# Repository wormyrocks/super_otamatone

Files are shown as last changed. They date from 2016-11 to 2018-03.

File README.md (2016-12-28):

# super_otamatone

Because the world needs a better Otamatone.

In order to set up build environment, you must have three .mk files from the Arduino Makefile repository in arduino/build_scripts

Teensy.mk
Common.mk
Arduino.mk

https://github.com/sudar/Arduino-Makefile

Running setup.sh in that directory should download them automatically.
You also need the Arduino application and Teensyduino, as well as the libraries specified in the Makefile.

This library uses my fork of the arduino-menusystem library, which can be found here.
https://github.com/wormyrocks/arduino-menusystem

It is included as a submodule.

'upload' script automates compilation, upload, and opening the serial monitor.

The last two require the tyc program. Find binaries here. https://github.com/Koromix/ty/releases
tyc should also be in /arduino/otamatone.

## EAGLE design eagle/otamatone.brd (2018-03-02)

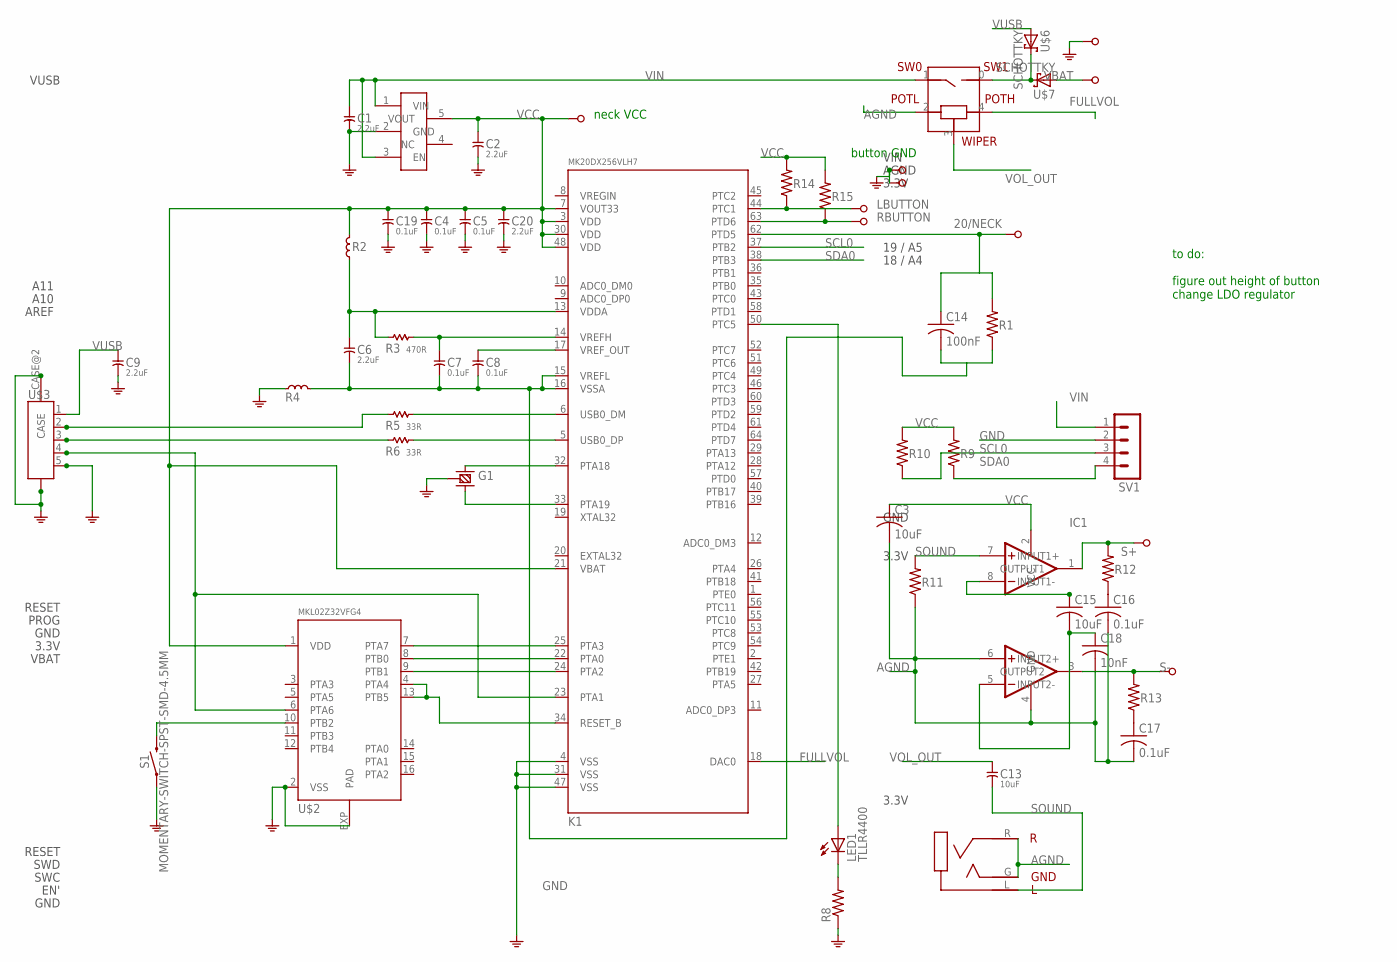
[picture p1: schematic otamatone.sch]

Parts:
B+: PIN; PTH_39MIL
B-: PIN; PTH_39MIL
C1, C2, C6, C9, C20: 2.2uF; C0603
C3, C13, C15: 10uF; C0603
C4, C5, C7, C8, C19: 0.1uF; C0402
C14: 100nF; C0402
C16, C17: 0.1uF; C0603
C18: 10nF; C0603
G1: CRYSTAL-; CRYS
IC1: TDA2822MSOP8; SOP8
K1: MK20DX256VLH7; LQFP64-05
LED1: TLLR4400; LED3MM
R1: 62K; R0402
R2, R4: FERRITE; L0603
R3: 470R; R0402
R5, R6: 33R; R0402
R8: R-US_R0603; R0603
R9, R10, R14, R15: 10K; R0402
R11: 10K; R0603
R12, R13: 4.7; R0603
S1: MOMENTARY-SWITCH-SPST-SMD-4.5MM; TACTILE_SWITCH_SMD_4.5MM
S+: PINSMT; SMD
S-: PINSMT; SMD
SV1: MA04-1
SX1, SX2, SX3, SX4: PIN; PTH_39MIL
U$1: P170S; 5PIN_POT
U$2: MKL02Z32VFG4; QFN16
U$3: VERT_USB; TALL_BOI
U$4: VERT_JACK; AUDIOJACK
U$5: AP2112K; SOT25
U$6, U$7: SCHOTTKY; LED-0805
Z+: PINSMT; SMD
Z-: PINSMT; SMD

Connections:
20/NECK: C14.1, K1.62 (PTD5), R1.2, Z-.P$1
AGND: C3.2, C6.2, C7.2, C8.2, C14.2, C16.2, C17.2, C18.2, IC1.4 (GND), IC1.6 (INPUT2+), K1.15 (VREFL), K1.16 (VSSA), R1.1, R4.2, R11.1, U$1.2 (POTL), U$4.G (GND), U$4.R
FULLVOL: K1.18 (DAC0), U$1.4 (POTH)
GND: B-.1, C1.2, C2.2, C4.2, C5.2, C9.2, C19.2, C20.2, G1.P$1 (GND), G1.P$4 (GND), K1.4 (VSS), K1.31 (VSS), K1.47 (VSS), R4.1, R8.1, S1.2 (1), S1.3 (1), SV1.2, SX1.1, SX3.1, U$2.2 (VSS), U$2.EXP (PAD), U$3.5, U$3.CASE, U$3.CASE@2 (CASE), U$5.2 (GND)
LBUTTON: K1.44 (PTC1), R14.1, SX2.1
unnamed: U$1.0 (SW1), U$6.- (C), U$7.- (C)
unnamed: K1.22 (PTA0), U$2.8 (PTB0)
unnamed: K1.24 (PTA2), U$2.9 (PTB1)
unnamed: G1.P$2 (1), K1.32 (PTA18)
unnamed: G1.P$3 (2), K1.33 (PTA19)
unnamed: C15.1, IC1.8 (INPUT1-)
unnamed: K1.25 (PTA3), U$2.7 (PTA7)
unnamed: S1.1 (2), S1.4 (2), U$2.10 (PTB2)
unnamed: C8.1, K1.17 (VREF_OUT)
unnamed: K1.34 (RESET_B), U$2.4 (PTA4), U$2.13 (PTB5)
unnamed: C7.1, K1.14 (VREFH), R3.2
unnamed: C6.1, K1.13 (VDDA), R2.1, R3.1
unnamed: C16.1, R12.1
unnamed: K1.23 (PTA1), U$2.6 (PTA6), U$3.4
unnamed: C17.1, R13.1
unnamed: C15.2, C18.1, IC1.5 (INPUT2-)
unnamed: K1.50 (PTC5), LED1.A
unnamed: LED1.K (C), R8.2
RBUTTON: K1.63 (PTD6), R15.1, SX4.1
S+: IC1.1 (OUTPUT1), R12.2, S+.P$1
S-: IC1.3 (OUTPUT2), R13.2, S-.P$1
SCL0: K1.37 (PTB2), R10.1, SV1.3
SDA0: K1.38 (PTB3), R9.1, SV1.4
SOUND: C13.2, IC1.7 (INPUT1+), R11.2, U$4.L
USB0_DM: K1.6 (USB0_DM), R5.2
USB0_DP: K1.5 (USB0_DP), R6.2
USB_M: R5.1, U$3.2
USB_P: R6.1, U$3.3
VBAT: B+.1, U$7.+ (A)
VCC: C2.1, C3.1, C4.1, C5.1, C19.1, C20.1, IC1.2 (VCC), K1.3 (VDD), K1.7 (VOUT33), K1.21 (VBAT), K1.30 (VDD), K1.48 (VDD), R2.2, R9.2, R10.2, R14.2, R15.2, U$2.1 (VDD), U$5.5 (VOUT), Z+.P$1
VIN: C1.1, SV1.1, U$1.1 (SW0), U$5.1 (VIN), U$5.3 (EN)
VOL_OUT: C13.1, U$1.3 (WIPER)
VUSB: C9.1, U$3.1, U$6.+ (A)

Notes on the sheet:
VIN
AGND
3.3V
19 / A5
18 / A4
GND
VBAT
RESET
PROG
A11
A10
AREF
VUSB
SWD
SWC
EN'
to do: figure out height of button change LDO regulator
neck VCC
button GND

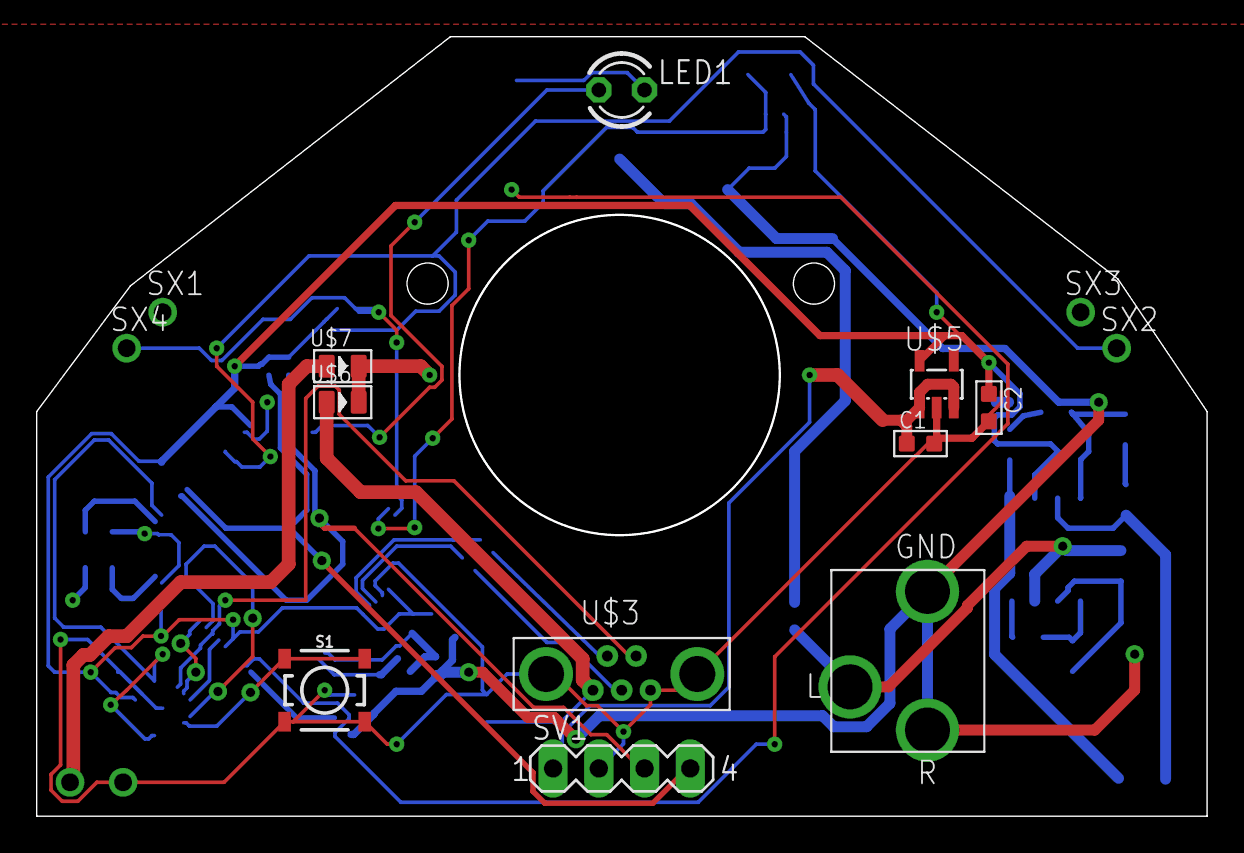
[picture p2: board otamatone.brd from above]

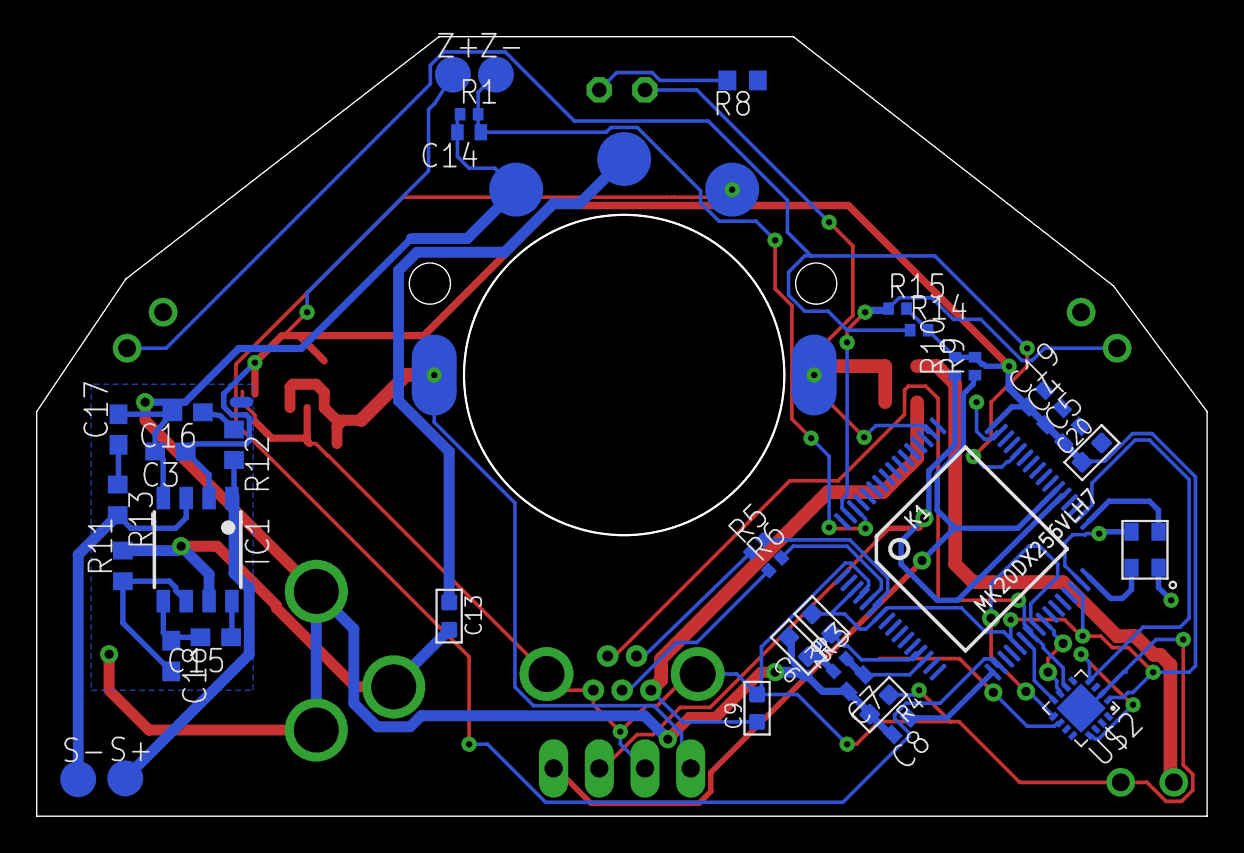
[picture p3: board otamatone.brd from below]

Board: 2 copper layers, 65.0 x 43.3 mm, 54 parts (38 on the bottom side), 38 nets.

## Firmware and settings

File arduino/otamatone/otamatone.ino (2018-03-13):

#include "MenuSystem.h"
#include "Synth.h"
#include "images.h"
#include <Adafruit_SSD1306.h>
Adafruit_SSD1306 oled(4);
// pin values
#define POT_PIN 20 // neck potentiometer reading
#define VOLUME_PIN 23 // volume potentiometer reading
#define BUTTON_LEFT 22 // left button
#define BUTTON_RIGHT 21 // right button
#define POLL_NECK_MICROS 6000 // interval between resistor polls (us)
#define POLL_VOLUME_MICROS 50000 // interval between volume pot polls (us)
#define EVENT_LOOP_DT 10 // time between loop() calls (ms)
// analogRead resolution
#define ADC_RES 16
#define RMIN 17 // minimum neck resistance, in kOhms
#define RMAX 195 // maximum neck resistance, in kOhms
#define PULL 62 // size of pull resistor, in kOhms
// values pertaining to ADC resolution
static const uint16_t max_adc = pow(2, ADC_RES) - 1;
static const uint16_t thresh_adc = max_adc / 10;
static const uint32_t neckscale = max_adc * PULL;
static const uint16_t neckscale_2 = max_adc / (RMAX - RMIN);
static uint16_t dt;
volatile uint16_t _pot_val;
static uint16_t pot_val;
static bool oto_tune_on = false;
static bool scrolling = false;
static bool select_on_release = false;
static bool edit_mode = false;
static bool new_vol = false;
// GUItool: begin automatically generated code
AudioSynthWaveform waveform1; // xy=464.2857360839844,727.8571605682373
AudioEffectEnvelope envelope1; // xy=701.2857360839844,635.8571605682373
AudioMixer4 mixer1; // xy=883,801
AudioOutputAnalog dac1; // xy=1017.1428642272949,667.1428813934326
AudioConnection patchCord1(waveform1, envelope1);
AudioConnection patchCord2(envelope1, 0, mixer1, 0);
AudioConnection patchCord3(mixer1, dac1);
// GUItool: end automatically generated code
Synth synth1(max_adc, & mixer1, & waveform1, & envelope1);
IntervalTimer neck_read_int;
IntervalTimer vol_read_int;
Bounce debounce_1 = Bounce();
Bounce debounce_2 = Bounce();
#include "mymenu.h"
void read_volume()
{
}

void button_1_pressed()
{
  if (edit_mode)
  {
    ms.display();
  }
}

void button_1_released()
{
  if (!edit_mode)
  {
    if (!synth1.playing)
    {
      synth1.change_octave(-1);
      disp_update_non_menu();
    }
  } else {
    ms.back();
    ms.display();
  }
}

void button_2_pressed()
{
  if (edit_mode)
  {
    synth1.mute(true);
    scrolling = true;
    select_on_release = true;
  }
}

void button_2_released()
{
  if (edit_mode)
  {
    synth1.mute(false);
    scrolling = false;
    if (select_on_release)
    {
      ms.select();
      ms.display();
    }
  }
  else
  {
    if (!synth1.playing)
    {
      synth1.change_octave(1);
      disp_update_non_menu();
    }
  }
}

void read_scale_neck()
{
  // resistance of neck, accounting for voltage division: PULL * (max_adc-N)/N
  _pot_val = analogRead(POT_PIN);
  if (_pot_val < thresh_adc)
    _pot_val = 0;
  else
  {
    _pot_val = (neckscale / _pot_val - PULL - RMIN) * neckscale_2;
  }
}

void setup()
{
  AudioMemory(18);
  pinMode(BUTTON_LEFT, INPUT);
  pinMode(BUTTON_RIGHT, INPUT);
  pinMode(POT_PIN, INPUT);
  pinMode(VOLUME_PIN, INPUT);
  // enter edit mode if both buttons are down at startup
  if (digitalRead(BUTTON_LEFT) == 0 && digitalRead(BUTTON_RIGHT) == 0)
  {
    edit_mode = 1;
  }
  edit_mode = 1;
  oled.begin(SSD1306_SWITCHCAPVCC, 0x3C);
  oled.clearDisplay();
  dac1.analogReference(INTERNAL);
  delay(50); // time for DAC voltage stable
  // pinMode(5, OUTPUT);
  // digitalWrite(5, HIGH); // turn on the amplifier
  // delay(10); // allow time to wake up
  debounce_1.attach(BUTTON_LEFT);
  debounce_2.attach(BUTTON_RIGHT);
  debounce_1.interval(5);
  debounce_2.interval(5);
  analogReadResolution(ADC_RES);
  neck_read_int.begin(read_scale_neck, POLL_NECK_MICROS);
  vol_read_int.begin(read_volume, POLL_VOLUME_MICROS);
  synth1.begin();
  presets[0].en = true;
  preset_menu_shown = presets[0].en;
  populate_menus();
  if (edit_mode)
  {
    ms.display();
  }
  else
  {
    oled.drawBitmap(0, 0, otamatone, 128, 64, 1);
    oled.display();
    delay(2000);
    disp_setup();
    disp_update_non_menu();
  }
}

void loop()
{
  debounce_1.update();
  debounce_2.update();
  dt = millis();
  noInterrupts();
  pot_val = _pot_val;
  interrupts();
  synth1.update(pot_val);
  // if (synth1.playing) Serial.println(synth1.get_freq());
  if (debounce_1.risingEdge())
    button_1_released();
  else if (debounce_1.fallingEdge())
    button_1_pressed();
  if (debounce_2.risingEdge())
    button_2_released();
  else if (debounce_2.fallingEdge())
    button_2_pressed();
  update_menu();
  while (millis() - dt < EVENT_LOOP_DT)
  {
  }
}

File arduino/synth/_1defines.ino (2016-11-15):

#include <MenuSystem.h>
#include <Adafruit_SSD1306.h>
#include <Bounce2.h>
#include <math.h>

//pin values
#define OLED_RESET 4              //unused
#define POT_PIN A10               //neck potentiometer reading
#define VOLUME_PIN 15             //volume potentiometer reading
#define BUTTON_LEFT 0             //left button
#define BUTTON_RIGHT 1            //right button

#define RMIN 23                   // minimum neck resistance, in kOhms
#define RMAX 190                  // maximum neck resistance, in kOhms
#define PULL 62                   // size of pull resistor, in kOhms
#define POLL_NECK_MICROS 6000     // interval between resistor polls (us)
#define POLL_VOLUME_MICROS 50000  // interval between volume pot polls (us)
#define EVENT_LOOP_DT 10          // time between loop() calls (ms)
#define FILTER_SIZE 8             // size of moving average buffer

//minimum and maximum frequencies in default range
#define FREQ_MIN_INIT 160.0 
#define FREQ_MAX_INIT 1450.0

//analogRead resolution
#define ADC_RES 16

//values pertaining to ADC resolution
static const int max_adc = pow(2,ADC_RES);
static const int thresh_adc = max_adc/10;

// ***** flags controlling overall state machine ***** //
static bool oto_tune_on = false;
static bool playing = false;
static bool scrolling = false;
static bool select_on_release = false;
static bool edit_mode = false;
static bool new_vol = false;

//ring buffer containing samples in moving average
static int avgs[FILTER_SIZE];

//pointer offset of oldest buffer contents
static int avg_ind = 0;

//time between cycles
static int dt;

//most recent value from potentiometer
static int pot_val;
//current volume
static int vol;

//minimum and maximum frequencies
static float freq_min = FREQ_MIN_INIT;
static float freq_max = FREQ_MAX_INIT;

//constant for equal temperament
static const float a_exp = pow(2, 1/12.0);
static const float log_a_exp = log(2)/12.0;
static const float a_tune = 440;

//current octave
static int octave = 0;
#define MAX_OCT 2
#define MIN_OCT -2

//neck scaling coefficients
static int neckscale = max_adc * PULL;
static int neckscale_2 = max_adc / (RMAX-RMIN);

//frequency coefficients
static float a_coeff;
static float b_coeff;
  
AudioControlSGTL5000 codec;
IntervalTimer neck_read_int;
IntervalTimer vol_read_int;

Bounce debounce_1 = Bounce();
Bounce debounce_2 = Bounce();

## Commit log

2016-10-30 switched to interrupts over polling
    [otamatone.xlsx]
2016-11-07 undid synth table
    [otamatone.xlsx]
2016-11-13 added octave switch functionality
2016-11-14 Begin working on menu framework.
2016-11-14 added sample code for navigating menus on-device
2016-11-14 Remove extraneous menu sample code.
2016-11-15 added oto tune and variable adc res
2016-11-15 compartmentalized arduino code into multiple files
2016-11-28 Add fritzing interposer design (shudder).
    [otamatone_breakout.fzz]
2016-11-28 Small updates to interposer pcb.
    [otamatone_breakout.fzz]
2016-11-28 Incremental update to breakout layout.
    [otamatone_breakout.fzz]
2016-11-29 Probably functional breakout pcb.
    [otamatone_breakout.fzz]
2016-11-29 Finished top half part labels.
    [otamatone_breakout.fzz]
2016-11-29 Minor tweaks.
    [otamatone_breakout.fzz]
2016-11-30 Added top and bottom silkscreens. This version of the breakout board was sent to OSHPark.
    [otamatone_breakout.fzz]
2016-12-02 Include new menu system. (Not tested on device, but compiles.)
2016-12-05 Updated pin assignments for PCB.
2016-12-28 Add small hole to board file.
    [otamatone_breakout.fzz]
2018-02-14 Overhauled file structure, began work on new PCB design
    [otamatone.brd, otamatone.sch, otamatone_breakout.fzz]
2018-02-15 Incremental updates to schematic and firmware
    [otamatone.brd, otamatone.sch]
2018-02-21 Updated schematics
    [otamatone.brd, otamatone.sch]
2018-02-28 sync changes
    [otamatone.brd, otamatone.sch]
2018-02-28 Updated gitignore and board contents
    unrouted components are now drc compliant, through hole components have been place
    [otamatone.brd, otamatone.sch]
2018-03-01 started laying out pcb
    [otamatone.brd, otamatone.sch]
2018-03-02 first pass at routing board
    [otamatone.brd, otamatone.sch]
2018-03-13 bug fixes to menu system, still not usable
    [otamatone.ino]

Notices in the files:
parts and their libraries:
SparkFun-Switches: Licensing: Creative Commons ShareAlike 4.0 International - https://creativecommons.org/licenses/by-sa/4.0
